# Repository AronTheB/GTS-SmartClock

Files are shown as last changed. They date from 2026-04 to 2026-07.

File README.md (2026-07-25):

# GTS-Smart Clock

Get To School (1920 x 1080 px)

<br><br/>

### DEMO VIDEO: https://youtu.be/dEGiFh21TzU

For some reason I always need to run to the bus stop so I can catch the bus, so instead of trying to leave earlier I designed the GTS Smart Clock which can tell me when to leave so I reach it without running and waiting.

For my first non guided Hardware project i made a Smart Clock that can tell me the time, but it also connects to the public transport API and tells me when i my next bus going and also when will i get to my destination if i leave at that moment. Other features will be added in the future

### The project uses a Xiao ESP32 C3, a OLED SSD1306 Screen, and a MxCherry switch with a keycap.

The clock is pretty simple to use. It has a single button which changes the current mode to the next one. The smart clock can be built by downloading the Gerber PCB files and buying them from a PCB printing company like JLCPCB or PCBWAY. You also need to buy the correct components which are linked in the BOM section, and 3d print the case or design a new one. After everything arrives solder everything to the board and upload the firmware to the ESP32. After that just put everything in the case like in the CAD model and connect it to power via a c-type cable. You can close the case by mainly screwing it in the screwhole with a 2mm x 5mm screw, but you could make it work with saller or a bit larger one (If your 3d printer cant print the icons on the top just remove them from the model and print it without them)

### You need to also set up a config.h file in the included folder. (you might have to rewrite the api part of the code if you are using a different api)

#define WIFI_SSID     "WIFINAME"

#define WIFI_PASSWORD "WIFIPASSPORT"

#define BKK_API_KEY   "PUBLICTRANSPORTAPIKEY"

#define BKK_STOP_ID    "BUSSTOPID"

#define BUS_ROUTE_SHORT_NAME "BUSNAME"

#define BUS_DIRECTION_HEADSIGN "BUSDESTINATION"

In the pcb the pins for the oled screen are reveresd so you need to use wires to wire them in instead of a header pin

## KIKAD
This is the Schematic:



<br></br>

This is the PCB layout and wiring:



<br></br>
## FUSION
This is the 3D Model of the case:



## Build



## BOM

| Name | Link | Price  | Quantity | Need To Buy? |
|---|---|---|---|---|
| XIAO ESP32 | [LINK](https://www.seeedstudio.com/Seeed-XIAO-ESP32C3-p-5431.html) | $5.13  | 1 | Yes |
| SSD1306 | [LINK](https://www.aliexpress.com/item/1005006141235306.html?spm=a2g0o.productlist.0.0.1ec2tPXFtPXFrn&mp=1) | $1.00  | 1 | Yes |
| Cherry MX Switch | [LINK](https://www.aliexpress.com/item/1005008586371182.html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) | $2.09  | 1 | No  |
| Cherry MX Keycaps  | [LINK](https://www.aliexpress.com/item/1005002906017844.html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) | $1.00  | 1 | No  |
| 3D Case | Printing Legion | Free + Shipping | 1 | Yes |
| PCB | JLCPCB | ≈ $5.00 | 1 | Yes |

**Total Cost:** $14.22

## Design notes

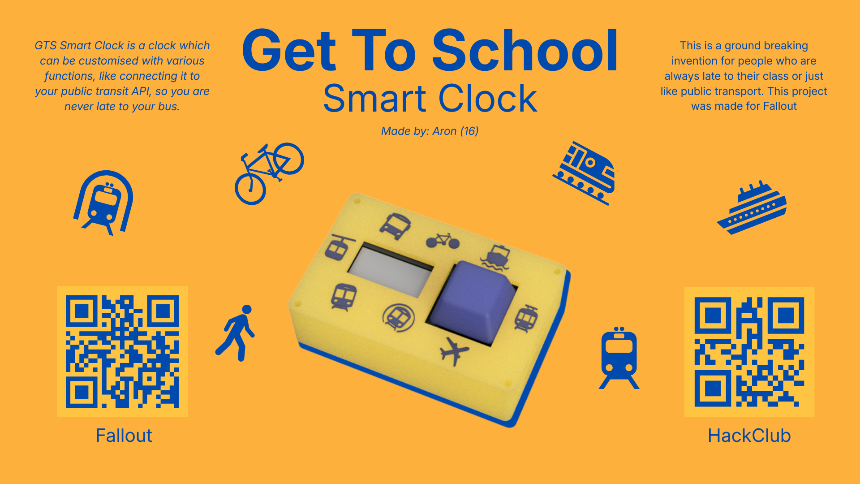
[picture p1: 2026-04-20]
SmartClock/Zine/Get To School(Horizontal).png

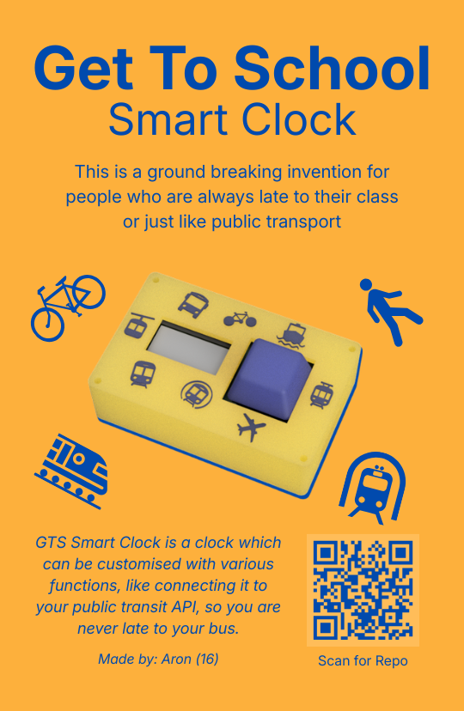
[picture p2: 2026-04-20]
SmartClock/Zine/Get To School(Vertical).png

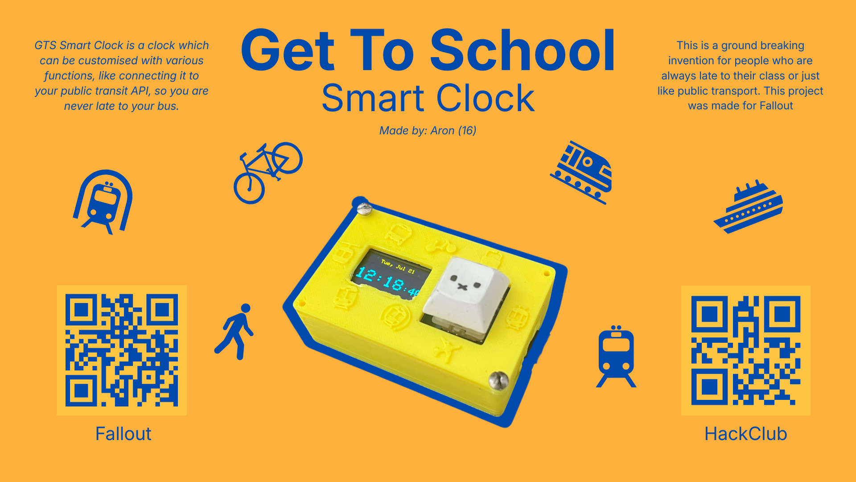
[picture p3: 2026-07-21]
SmartClock/Zine/Get To School (1920 x 1080 px).png

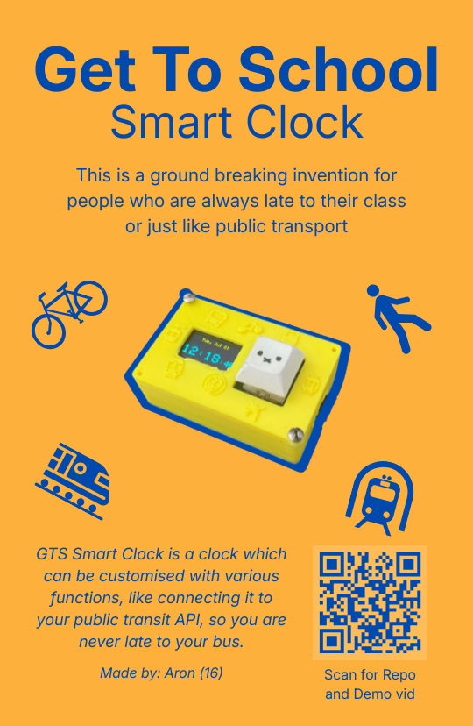
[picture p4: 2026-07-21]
SmartClock/Zine/Get To School.png

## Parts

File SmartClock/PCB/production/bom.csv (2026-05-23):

Designator | Footprint | Quantity | Value | LCSC Part #
OL1 | MODULE_DM-OLED096-636 | 1 | OLED
SW1 | SW_Cherry_MX_1.00u_PCB | 1 | SW_Push
U2 | XIAO-ESP32-C3-DIP | 1 | XIAO-ESP32-C3-DIP

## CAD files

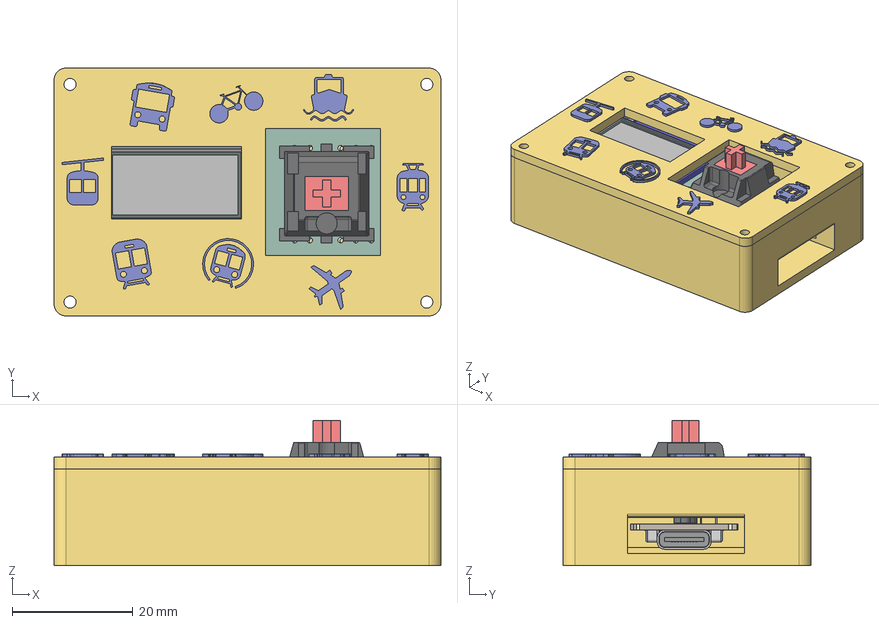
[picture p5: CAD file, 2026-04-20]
SmartClock/CAD/GTFTS-SmartClock-Entire.step
64.0 x 41.0 x 24.0 mm

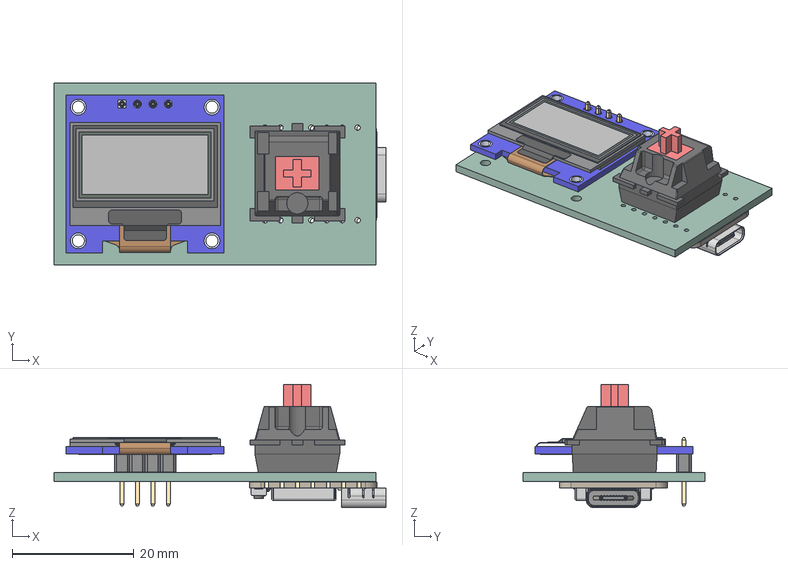
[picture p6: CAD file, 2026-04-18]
SmartClock/PCB/SmartClock.step
54.6 x 30.0 x 20.3 mm
DM-OLED096-636_Module
DM-OLED096-636_Panel
BOSS-EXTRUDE14_8_
BOSS-EXTRUDE7_4_
BOSS-EXTRUDE7_3_
BOSS-EXTRUDE14_4_
BOSS-EXTRUDE14_2_
BOSS-EXTRUDE14_11_
BOSS-EXTRUDE7_7_
BOSS-EXTRUDE14_9_
BOSS-EXTRUDE14_3_
BOSS-EXTRUDE14_7_
MIRROR2
BOSS-EXTRUDE14_5_
BOSS-EXTRUDE14_12_
BOSS-EXTRUDE7_8_
BOSS-EXTRUDE7_1_
BOSS-EXTRUDE14_10_
BOSS-EXTRUDE7_9_
BOSS-EXTRUDE14_6_
BOSS-EXTRUDE14_1_
BOSS-EXTRUDE7_6_
BOSS-EXTRUDE7_2_
CUT-EXTRUDE5
BOSS-EXTRUDE7_5_
U.FL Connector v1
Button (1) x 2
Shield
SmartClock_PCB

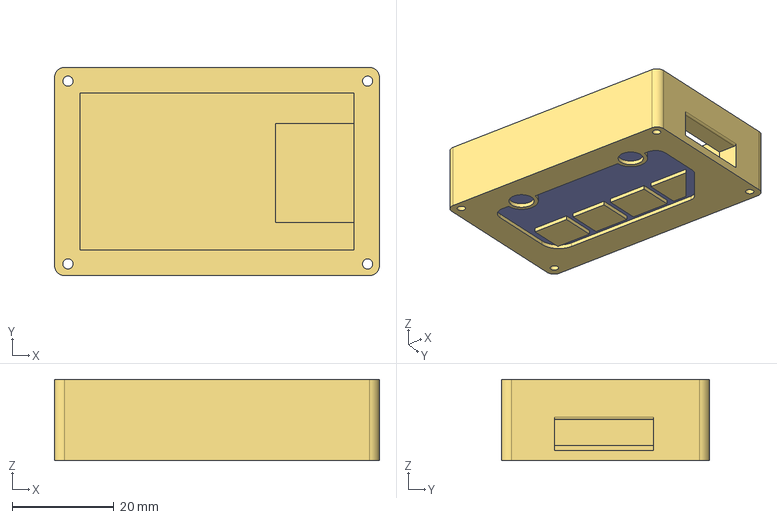
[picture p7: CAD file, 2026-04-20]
SmartClock/CAD/GTFTS-SmartClock-Bottom.step
64.0 x 41.0 x 16.0 mm

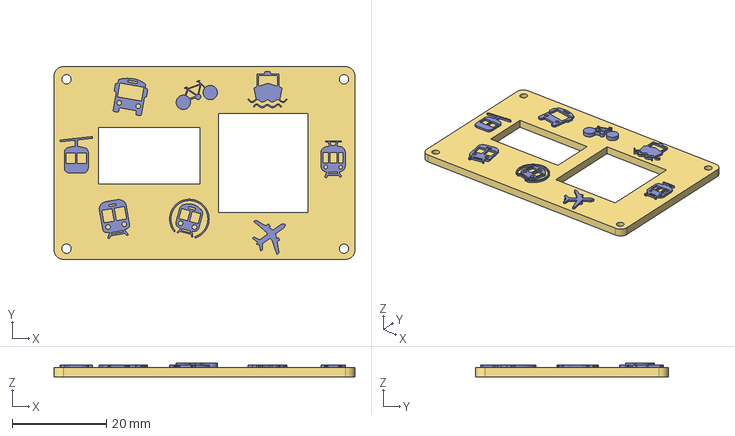
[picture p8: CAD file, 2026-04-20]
SmartClock/CAD/GTFTS-SmartClock-Top.step
64.0 x 41.0 x 2.96 mm

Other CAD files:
SmartClock/SmartClock.f3z
SmartClock/SmartClockBottom.f3d
SmartClock/SmartClockTop.f3d

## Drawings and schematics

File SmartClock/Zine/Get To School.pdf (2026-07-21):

# Get To School

# Smart Clock

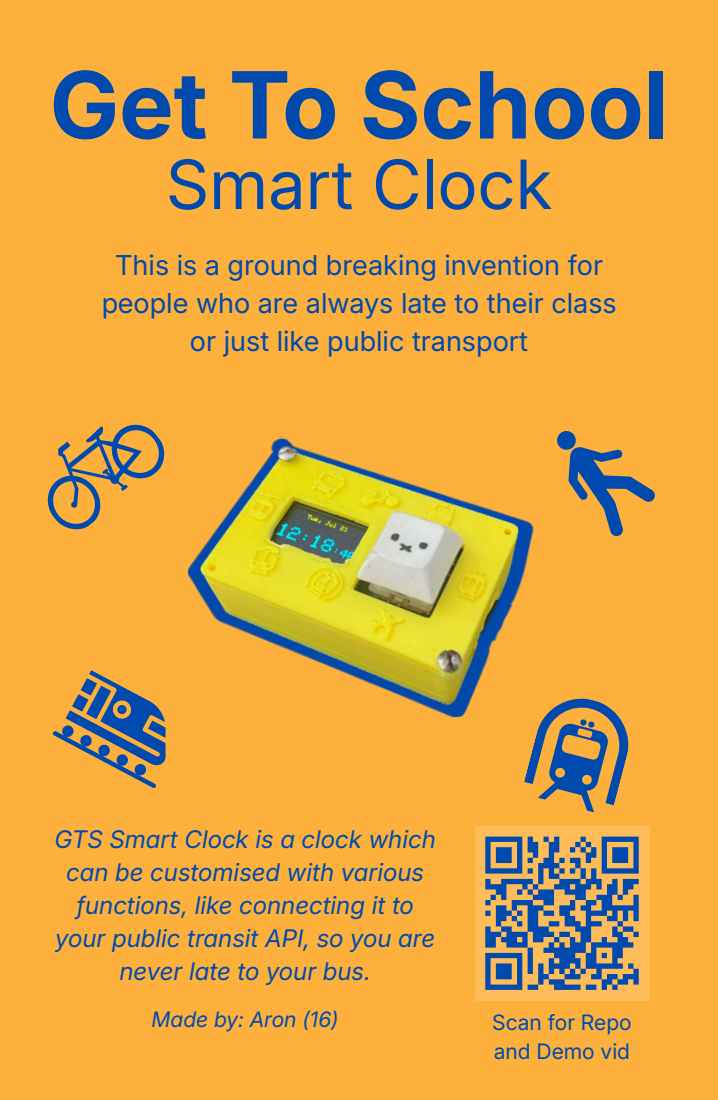
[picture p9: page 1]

This is a ground breaking invention for
people who are always late to their class
or just like public transport

GTS Smart Clock is a clock which
can be customised with various
functions, like connecting it to
your public transit API, so you are
never late to your bus.

Made by: Aron (16)

Scan for Repo
and Demo vid

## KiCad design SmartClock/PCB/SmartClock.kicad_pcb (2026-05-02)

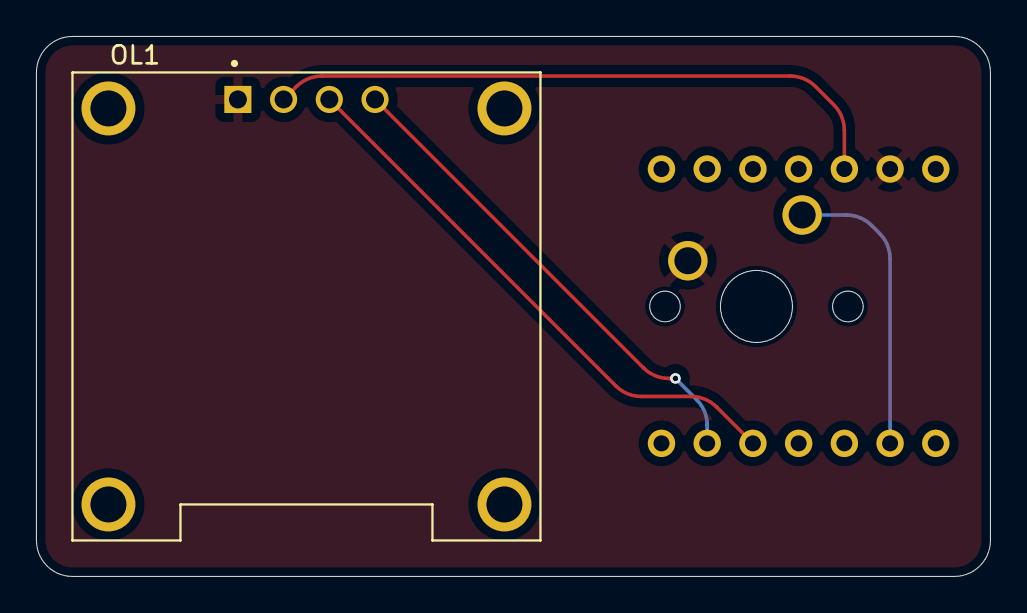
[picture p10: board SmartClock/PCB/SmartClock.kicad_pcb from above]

Board: 2 copper layers, 53.0 x 30.0 mm, 3 parts (1 on the bottom side), 5 nets.

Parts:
OL1: OLED; MODULE_DM-OLED096-636
SW1: SW_Push; SW_Cherry_MX_1.00u_PCB
U2: XIAO-ESP32-C3-DIP

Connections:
GND: OL1.1 (GND), SW1.2, U2.13 (GND)
unnamed: OL1.3 (SCL), U2.5 (GPIO6_D4_SDA)
unnamed: OL1.4 (SDA), U2.6 (GPIO7_D5_SCL)
unnamed: OL1.2 (VCC), U2.12 (3V3)
unnamed: SW1.1, U2.2 (GPIO3_A1_D1)

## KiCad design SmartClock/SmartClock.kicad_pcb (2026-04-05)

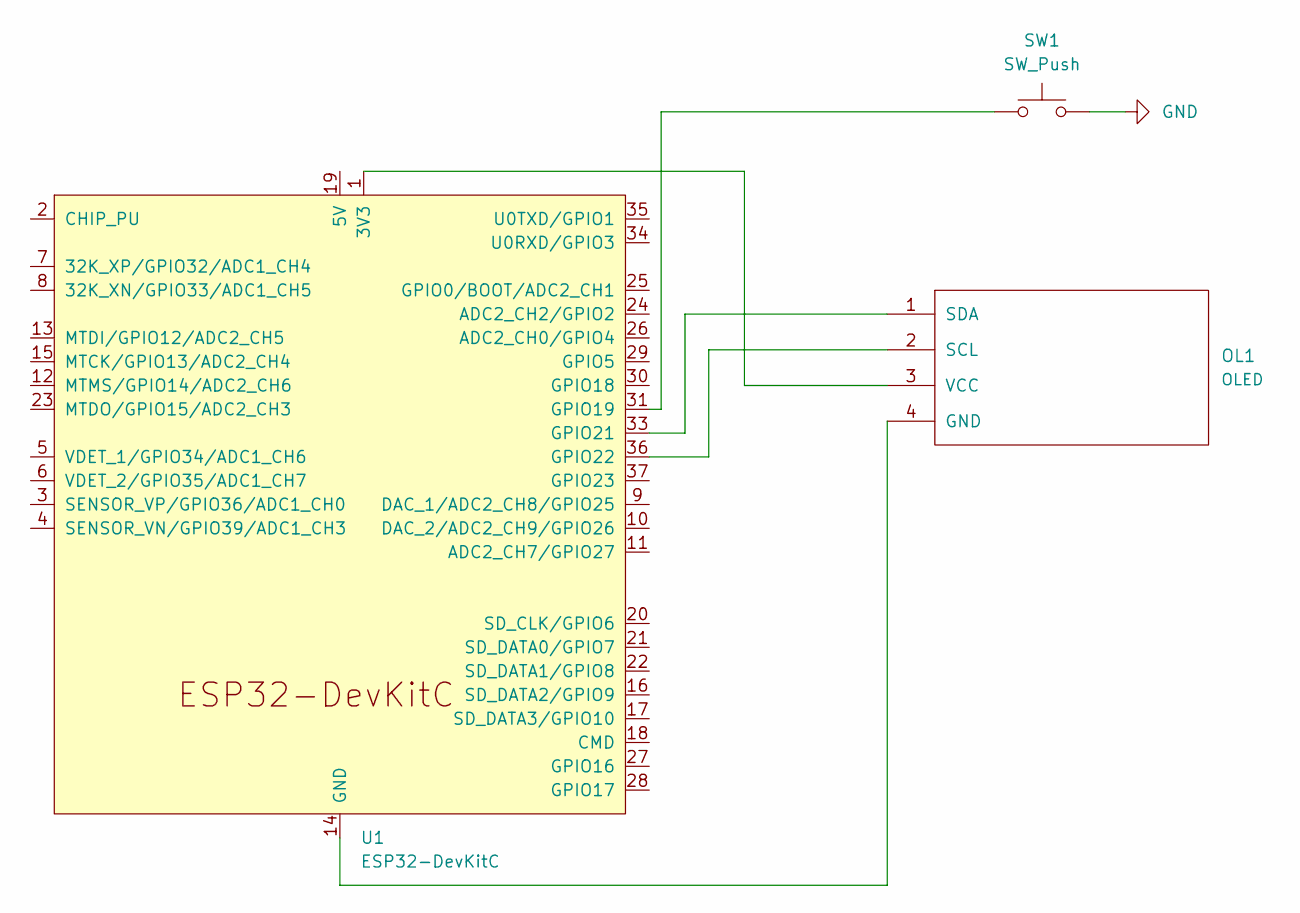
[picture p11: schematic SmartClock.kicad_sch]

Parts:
OL1: OLED
SW1: SW_Push; SW_Cherry_MX_1.00u_PCB
U1: ESP32-DevKitC

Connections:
GND: SW1.2
unnamed: OL1.4 (GND), U1.14 (GND), U1.32 (GND), U1.38 (GND)
unnamed: OL1.2 (SCL), U1.36 (GPIO22)
unnamed: OL1.1 (SDA), U1.33 (GPIO21)
unnamed: OL1.3 (VCC), U1.1 (3V3)
unnamed: SW1.1, U1.31 (GPIO19)

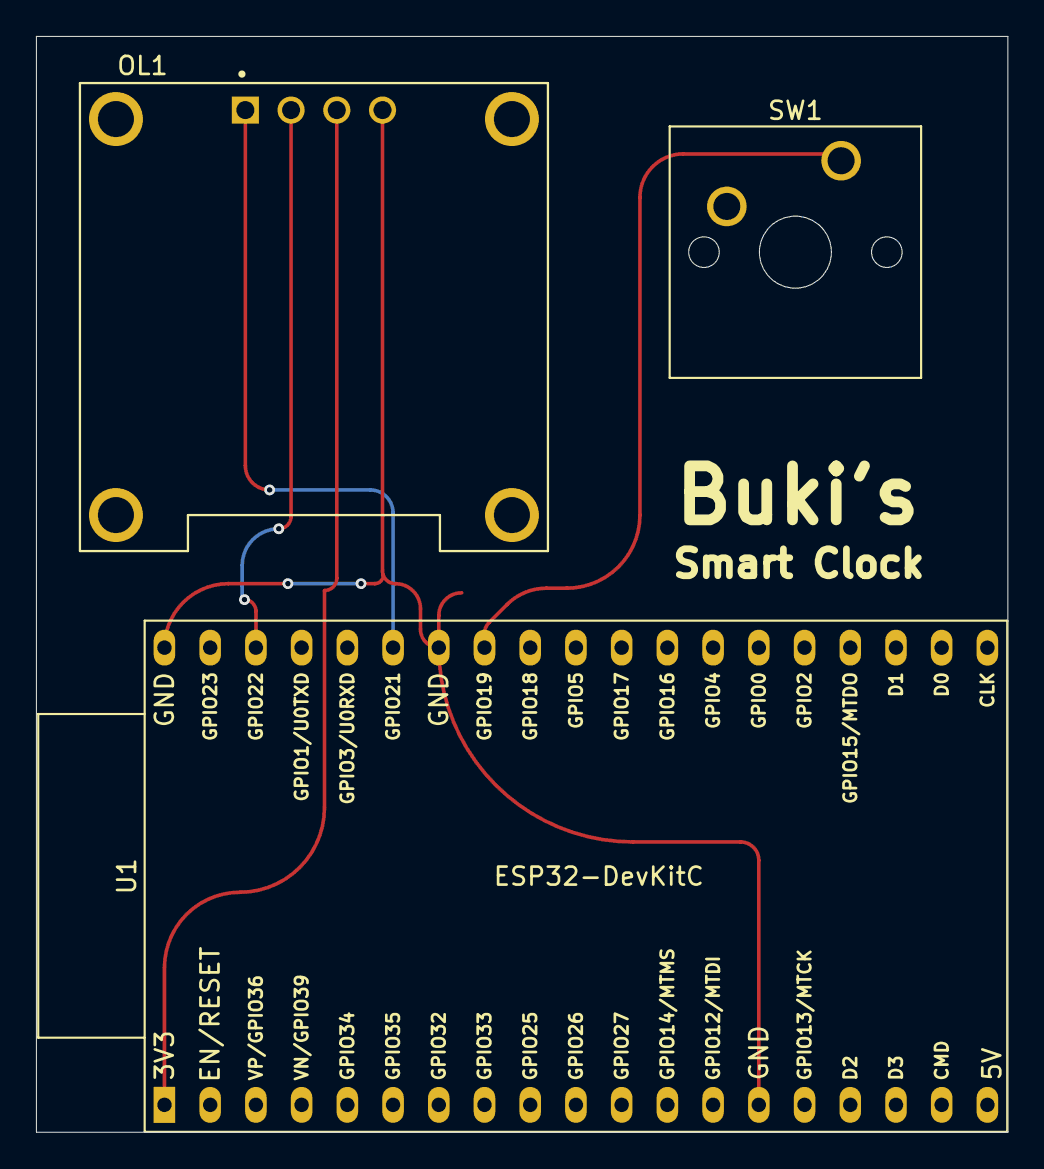
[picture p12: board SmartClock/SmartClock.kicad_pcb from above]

Board: 2 copper layers, 54.0 x 60.9 mm, 3 parts (0 on the bottom side), 5 nets.

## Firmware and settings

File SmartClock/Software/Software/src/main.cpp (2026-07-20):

#include <Arduino.h>
#include <Wire.h>
#include <Adafruit_GFX.h>
#include <Adafruit_SSD1306.h>
#include <WiFi.h>
#include <time.h>
#include <HTTPClient.h>
#include <ArduinoJson.h>
#include <WiFiClientSecure.h>
#include "config.h"


const long UTC_OFFSET_SEC = 7200;
const int DAYLIGHT_OFFSET_SEC = 0;
const char* NTP_SERVER = "pool.ntp.org";

#define SCREEN_WIDTH 128
#define SCREEN_HEIGHT 64
#define OLED_RESET     -1
#define SCREEN_ADDRESS 0x3C
#define I2C_SDA_PIN D5
#define I2C_SCL_PIN D4
#define BUTTON_PIN D2

enum ScreenView { VIEW_CLOCK, VIEW_BUS };
ScreenView currentView = VIEW_CLOCK;
bool lastButtonState = HIGH;
time_t nextBusDepartureEpoch = 0;
unsigned long lastBkvFetch = 0;
const unsigned long BKV_FETCH_INTERVAL_MS = 60000;

Adafruit_SSD1306 display(SCREEN_WIDTH, SCREEN_HEIGHT, &Wire, OLED_RESET);

void showStatus(const char* message) {
  display.clearDisplay();
  display.setTextSize(1);
  display.setCursor(0, 0);
  display.println(message);
  display.display();
}

void connectToWiFi() {
  Serial.print("Connecting to WiFi");
  WiFi.begin(WIFI_SSID, WIFI_PASSWORD);
  String dots = "";
  while (WiFi.status() != WL_CONNECTED) {
    delay(500);
    Serial.print(".");
    dots += ".";
    if (dots.length() > 10) dots = "";
    showStatus(("Connecting to WiFi" + dots).c_str());
  }
  Serial.println("\nConnected to WiFi");
  showStatus("WiFi connected");
}

void syncNTP() {
  configTime(UTC_OFFSET_SEC, DAYLIGHT_OFFSET_SEC, NTP_SERVER);
  Serial.println("Syncing with NTP server");
  struct tm t;
  String dots = "";
  while (!getLocalTime(&t)) {
    delay(500);
    Serial.print(".");
    dots += ".";
    if (dots.length() > 10) dots = "";
    showStatus(("Syncing NTP" + dots).c_str());
  }
  Serial.println("synced");
  showStatus("NTP synced");
}

void bkvAPI(){
  if (WiFi.status() != WL_CONNECTED) return;
  
  WiFiClientSecure client;
  client.setInsecure();

  HTTPClient http;
  String url = String("https://futar.bkk.hu/api/query/v1/ws/otp/api/where/arrivals-and-departures-for-stop")
    + "?key=" + BKK_API_KEY
    + "&version=3&appVersion=1&stopId=" + BKK_STOP_ID
    + "&onlyDepartures=true&minutesAfter=60";

  if (!http.begin(client, url)) {
    Serial.println("bkvAPI: http.begin failed");
    return;
  }

  int code = http.GET();
  if (code != HTTP_CODE_OK) {
    Serial.printf("bkvAPI: HTTP error %d\n", code);
    http.end();
    return;
  }

  JsonDocument filter;
  filter["data"]["entry"]["stopTimes"][0]["tripId"] = true;
  filter["data"]["entry"]["stopTimes"][0]["stopHeadsign"] = true;
  filter["data"]["entry"]["stopTimes"][0]["predictedDepartureTime"] = true;
  filter["data"]["entry"]["stopTimes"][0]["departureTime"] = true;
  filter["data"]["references"]["trips"]["*"]["routeId"] = true;
  filter["data"]["references"]["trips"]["*"]["tripHeadsign"] = true;
  filter["data"]["references"]["routes"]["*"]["shortName"] = true;

  JsonDocument doc;
  DeserializationError err = deserializeJson(doc, http.getStream(), DeserializationOption::Filter(filter));
  http.end();

  if (err) {
    Serial.printf("bkvAPI: JSON parse failed: %s\n", err.c_str());
    return;
  }

  JsonArray stopTimes = doc["data"]["entry"]["stopTimes"];
  JsonObject trips = doc["data"]["references"]["trips"];
  JsonObject routes = doc["data"]["references"]["routes"];

  time_t now;
  time(&now);

  time_t earliest = 0;
  for (JsonObject st : stopTimes) {
    const char* tripId = st["tripId"];
    if (!tripId || !trips[tripId].is<JsonObject>()) continue;

    const char* routeId = trips[tripId]["routeId"];
    if (!routeId || !routes[routeId].is<JsonObject>()) continue;

    const char* shortName = routes[routeId]["shortName"];
    if (!shortName || strcmp(shortName, BUS_ROUTE_SHORT_NAME) != 0) continue;

    const char* headsign = st["stopHeadsign"] | trips[tripId]["tripHeadsign"].as<const char*>();
    if (!headsign || strstr(headsign, BUS_DIRECTION_HEADSIGN) == nullptr) continue;

    time_t dep = st["predictedDepartureTime"] | (time_t)st["departureTime"];
    if (dep <= now) continue;

    if (earliest == 0 || dep < earliest) earliest = dep;
  }

  nextBusDepartureEpoch = earliest;
}

void setup() {
  Serial.begin(115200);
  delay(1500);
  Serial.println("Boot: starting");

  pinMode(BUTTON_PIN, INPUT_PULLUP);

    Serial.println("Boot: I2C init");
    Wire.begin(I2C_SDA_PIN, I2C_SCL_PIN);

    Serial.println("Boot: I2C scan");
    int devicesFound = 0;
    for (uint8_t addr = 1; addr < 127; addr++) {
      Wire.beginTransmission(addr);
      if (Wire.endTransmission() == 0) {
        Serial.print("  found device at 0x");
        Serial.println(addr, HEX);
        devicesFound++;
      }
    }
    if (devicesFound == 0) {
      Serial.println("  no I2C devices found - check SDA/SCL/VCC/GND wiring");
    }

    Serial.println("Boot: display init");
    if(!display.begin(SSD1306_SWITCHCAPVCC, SCREEN_ADDRESS)) {
      Serial.println(F("SSD1306 init failed - continuing without display"));
    } else {
      Serial.println("Boot: display OK");
    }
    display.clearDisplay();
    display.setTextColor(SSD1306_WHITE);
    display.display();
    showStatus("Booting...");

  connectToWiFi();
  syncNTP();

  bkvAPI();
  lastBkvFetch = millis();
}

unsigned long lastButtonDebugPrint = 0;

void loop() {

  if (millis() - lastButtonDebugPrint > 1000) {
    lastButtonDebugPrint = millis();
    Serial.print("Button pin raw state: ");
    Serial.println(digitalRead(BUTTON_PIN));
  }

  bool currentButtonState = digitalRead(BUTTON_PIN);
  if (lastButtonState == HIGH && currentButtonState == LOW) {
    Serial.println("Button pressed");
    currentView = (currentView == VIEW_CLOCK) ? VIEW_BUS : VIEW_CLOCK;
    delay(50);
  }
  lastButtonState = currentButtonState;

  if (millis() - lastBkvFetch > BKV_FETCH_INTERVAL_MS) {
  lastBkvFetch = millis();
  bkvAPI();
  }


  struct tm timeinfo;
  if (getLocalTime(&timeinfo)) {
    display.clearDisplay();

    if (currentView == VIEW_CLOCK) {
      char dateStr[16];
      strftime(dateStr, sizeof(dateStr), "%a, %b %d", &timeinfo);
      display.setTextSize(1);
      display.setCursor((128 - strlen(dateStr) * 6) / 2, 4);
      display.print(dateStr);
      display.setTextSize(3);
      display.setCursor(1, 29);
      display.printf("%02d:%02d", timeinfo.tm_hour, timeinfo.tm_min);
      display.setTextSize(2);
      display.setCursor(91, 36);
      display.printf(":%02d", timeinfo.tm_sec);
    } else { // VIEW_BUS
      // Top: current time, where the date sits on the clock view
      char timeStr[8];
      strftime(timeStr, sizeof(timeStr), "%H:%M", &timeinfo);
      display.setTextSize(1);
      display.setCursor((128 - strlen(timeStr) * 6) / 2, 4);
      display.print(timeStr);

      // Big area: MM:SS countdown to the next outbound 260
      display.setTextSize(3);
      if (nextBusDepartureEpoch > 0) {
        time_t now;
        time(&now);
        long secsLeft = (long)(nextBusDepartureEpoch - now);
        if (secsLeft < 0) secsLeft = 0;
        long mm = secsLeft / 60;
        long ss = secsLeft % 60;
        char cd[8];
        snprintf(cd, sizeof(cd), "%02ld:%02ld", mm, ss);
        display.setCursor((128 - strlen(cd) * 18) / 2, 29);
        display.print(cd);
      } else {
        display.setCursor((128 - 2 * 18) / 2, 29);
        display.print("--");
      }
    }

    display.display();
  }
  delay(200);
}

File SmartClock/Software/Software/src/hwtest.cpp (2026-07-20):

// Testing code for the ESP32
#include <Arduino.h>
#include <Wire.h>
#include <Adafruit_GFX.h>
#include <Adafruit_SSD1306.h>
#include <WiFi.h>

// PCB routes the OLED with SDA on D5 and SCL on D4 (swapped vs. XIAO default)
#define I2C_SDA_PIN D5
#define I2C_SCL_PIN D4

Adafruit_SSD1306 display(128, 64, &Wire, -1);
bool haveDisplay = false;

const int dGpio[] = {2, 3, 4, 5, 21, 20, 8, 9, 10};
const char* dName[] = {"D0", "D1", "D2", "D3", "D6", "D7", "D8", "D9", "D10"};
const int nPins = sizeof(dGpio) / sizeof(dGpio[0]);

void setup() {
  Serial.begin(115200);
  delay(2000);
  Serial.println("\n=== XIAO ESP32C3 pin monitor (OLED feedback) ===");

  // Line-state check before I2C claims the pins: with pullups, a healthy idle
  // bus reads HIGH on both lines. LOW = shorted to GND or held by a stuck device.
  pinMode(6, INPUT_PULLUP);
  pinMode(7, INPUT_PULLUP);
  delay(10);
  Serial.printf("SCL (D4/GPIO6) idle: %s\n", digitalRead(6) ? "HIGH (good)" : "LOW  <-- STUCK! short or held");
  Serial.printf("SDA (D5/GPIO7) idle: %s\n", digitalRead(7) ? "HIGH (good)" : "LOW  <-- STUCK! short or held");

  Wire.begin(I2C_SDA_PIN, I2C_SCL_PIN);
  Wire.setTimeOut(50); // fail pings fast when the bus is stuck
  haveDisplay = display.begin(SSD1306_SWITCHCAPVCC, 0x3C);
  Serial.printf("display: %s\n", haveDisplay ? "OK" : "NOT FOUND");
  if (haveDisplay) {
    display.clearDisplay();
    display.setTextColor(SSD1306_WHITE);
    display.setTextSize(1);
    display.setCursor(0, 0);
    display.println("Pin monitor ready");
    display.println("Touch pin to GND...");
    display.display();
  }

  for (int i = 0; i < nPins; i++) pinMode(dGpio[i], INPUT_PULLUP);

  Serial.println("WiFi scan...");
  if (haveDisplay) {
    display.clearDisplay();
    display.setTextSize(1);
    display.setCursor(0, 0);
    display.println("WiFi scan...");
    display.display();
  }
  WiFi.mode(WIFI_STA);
  int n = WiFi.scanNetworks();
  Serial.printf("%d networks found\n", n);
  if (haveDisplay) {
    display.clearDisplay();
    display.setCursor(0, 0);
    display.printf("%d networks:\n", n);
  }
  for (int i = 0; i < n && i < 6; i++) {
    Serial.printf("  %s  RSSI %d dBm\n", WiFi.SSID(i).c_str(), WiFi.RSSI(i));
    if (haveDisplay) display.printf("%s %d\n", WiFi.SSID(i).substring(0, 15).c_str(), WiFi.RSSI(i));
  }
  for (int i = 6; i < n; i++) Serial.printf("  %s  RSSI %d dBm\n", WiFi.SSID(i).c_str(), WiFi.RSSI(i));
  if (haveDisplay) {
    display.display();
    delay(8000); // leave scan results readable before pin monitor takes over
  }
  WiFi.scanDelete();
}

String lastEvent = "none yet";
int eventCount = 0;

void loop() {
  // Live I2C wiggle test: ping the OLED twice a second, report every flip.
  static unsigned long lastPing = 0;
  static int busOk = -1;
  static int flips = 0;
  if (millis() - lastPing > 500) {
    lastPing = millis();
    // Idle-line readback in the loop, where USB-CDC is fully up (the boot-time
    // print gets eaten during re-enumeration). Both LOW => OLED lost VCC.
    Serial.printf("  idle lines: SCL(D4)=%d SDA(D5)=%d\n", digitalRead(6), digitalRead(7));
    Wire.beginTransmission(0x3C);
    int ok = (Wire.endTransmission() == 0) ? 1 : 0;
    if (ok != busOk) {
      flips++;
      busOk = ok;
      Serial.printf("### DISPLAY BUS %s (flip #%d, t=%lus)\n", ok ? "OK" : "LOST", flips, millis() / 1000);
      if (ok) {
        haveDisplay = display.begin(SSD1306_SWITCHCAPVCC, 0x3C);
        if (haveDisplay) {
          display.clearDisplay();
          display.setTextColor(SSD1306_WHITE);
          display.setTextSize(2);
          display.setCursor(0, 0);
          display.println("BUS OK");
          display.printf("flip %d", flips);
          display.display();
        }
      } else {
        haveDisplay = false;
      }
    }
  }

  static int last[16];
  static bool first = true;
  int now[16];
  bool changed = false;
  String lows = "";

  for (int i = 0; i < nPins; i++) {
    now[i] = digitalRead(dGpio[i]);
    if (first || now[i] != last[i]) changed = true;
    if (!first && last[i] == 1 && now[i] == 0) {
      lastEvent = dName[i];
      eventCount++;
    }
    if (now[i] == 0) {
      lows += dName[i];
      lows += " ";
    }
    last[i] = now[i];
  }
  first = false;

  static unsigned long lastPrint = 0;
  if (changed || millis() - lastPrint > 2000) {
    lastPrint = millis();
    for (int i = 0; i < nPins; i++) Serial.printf("%s=%d ", dName[i], last[i]);
    Serial.println(changed ? "  <-- CHANGE" : "");
  }

  if (haveDisplay && changed) {
    display.clearDisplay();
    display.setTextSize(1);
    display.setCursor(0, 0);
    display.println(lows.length() > 0 ? "CONTACT NOW:" : "All pins HIGH");
    if (lows.length() > 0) {
      display.setTextSize(3);
      display.setCursor(0, 10);
      display.println(lows);
    }
    display.setTextSize(1);
    display.setCursor(0, 40);
    display.println("Last contact seen:");
    display.setTextSize(2);
    display.setCursor(0, 50);
    display.print(lastEvent);
    display.setTextSize(1);
    display.printf("  (%dx)", eventCount);
    display.display();
  }
  delay(30);
}

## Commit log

2026-04-05 added stuff
    [SmartClock.kicad_pcb, SmartClock.kicad_sch, SmartClockTop.f3d]
2026-04-05 Added Fusion files
    [SmartClock.f3z, SmartClockBottom.f3d, SmartClockTop.f3d]
2026-04-05 added framework
2026-04-13 Add Bill of Materials section to READMEbom
2026-04-14 changed pcb
    [SmartClock.kicad_pcb, SmartClock.kicad_sch]
2026-04-20 Update ESP32 DevKitC link in BOM
2026-04-20 Remove BOM section header from README
    Removed the BOM section header from the README.
2026-04-20 3d models + remmove
    [GTFTS-SmartClock-Bottom.stl, GTFTS-SmartClock-Top.stl, SmartClock.f3z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]
2026-04-20 added step files
    [GTFTS-SmartClock-Bottom.step, GTFTS-SmartClock-Bottom.stl, GTFTS-SmartClock-Entire.step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]
2026-04-20 Update README with 3D printing instructions
    Added note about 3D printing icons on the clock case.
2026-04-22 fixed issues
    [SmartClock.kicad_pcb, SmartClock.kicad_sch]
2026-04-22 added gerber files
    [SmartClock-B_Cu.gbr, SmartClock-B_Mask.gbr, SmartClock-B_Paste.gbr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]
2026-04-22 added button functionality
2026-07-20 Add BKK bus-departure view and fetch departures at boot
    Show a countdown to the next outbound 260 alongside the clock,
    switchable with the button. Fetch once at boot so the view is
    populated immediately, and don't hang boot if the display is absent.
